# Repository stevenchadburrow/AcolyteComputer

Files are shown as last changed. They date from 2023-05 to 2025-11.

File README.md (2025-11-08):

# AcolyteComputer
Acolyte 6502 "Homebrew" Computer

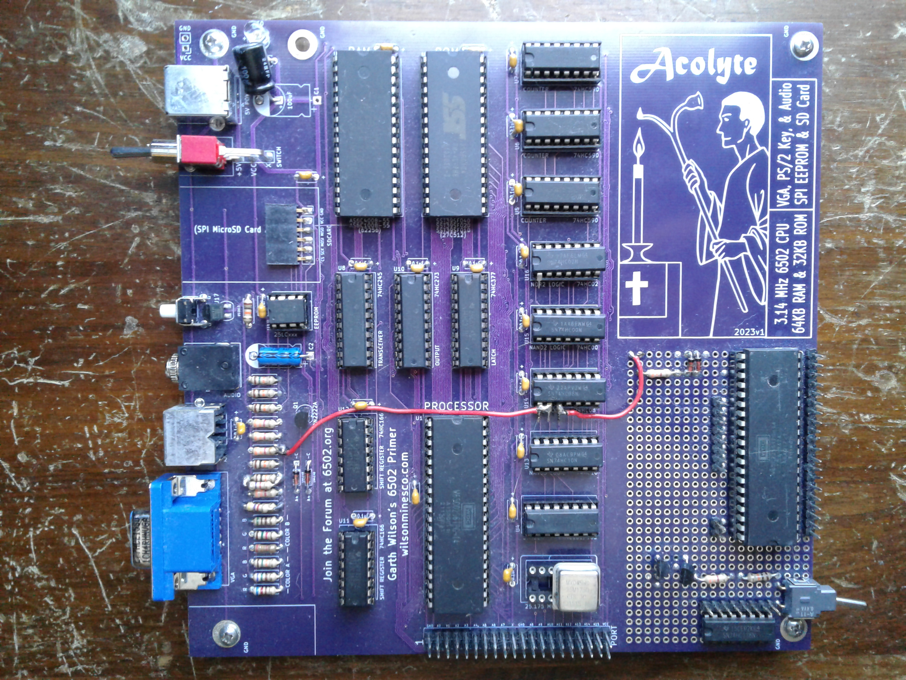
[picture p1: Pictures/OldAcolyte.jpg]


Runs a W65C02 Microprocessor at 3.14 MHz.
Has 64K SRAM and 32K FlashROM.

VGA resolution of 320x240 4-Colors.
PS/2 Keyboard support built in.
One-voice square wave audio.
SPI EEPROM is built into the board.
Socket for a MicroSD Card Adapter.
Optional VIA Expansion.
It is powered with 5V USB.

The goal is that this board would cost less than $100 to assemble.
There are also no CPLD or FPGA chips used, everything besides the 6502/RAM/ROM are 74HC' logic chips.

All files included here are hereby released into the Public Domain.  Anyone is free to copy, modify, publish, use, compile, sell, or distribute these files for any purpose, commercial or non-commercial, and by any means.  These files are provided "as is", without warranty of any kind.  In no event shall the author be liable for any claim, damages, or other liability.

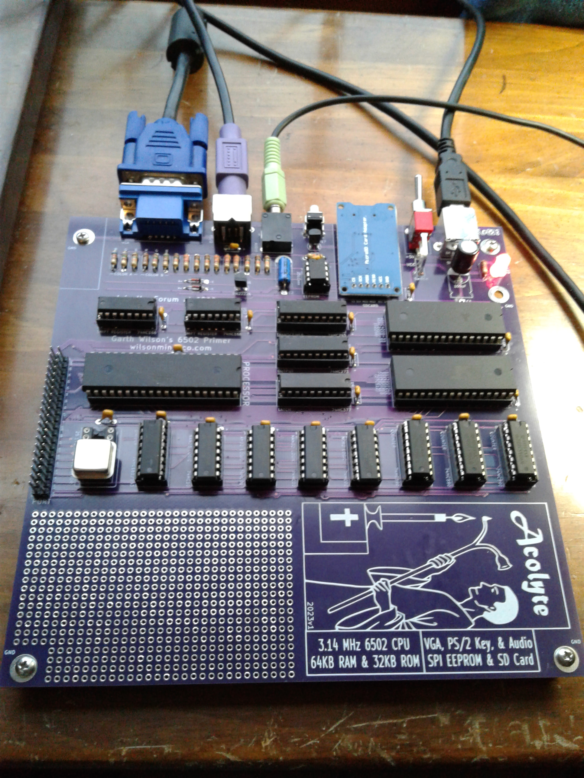
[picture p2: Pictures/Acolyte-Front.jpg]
<br>
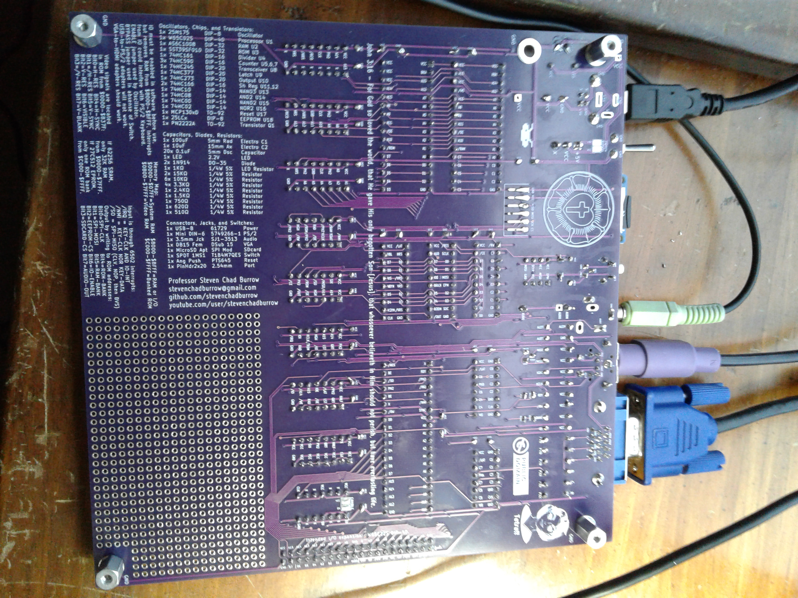
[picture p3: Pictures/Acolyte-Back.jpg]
<br>
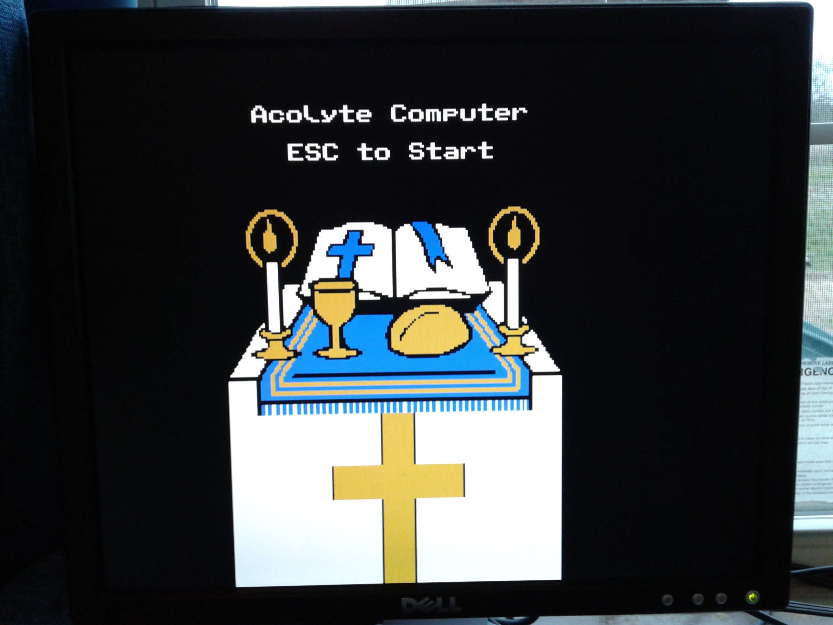
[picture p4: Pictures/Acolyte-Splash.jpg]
<br>
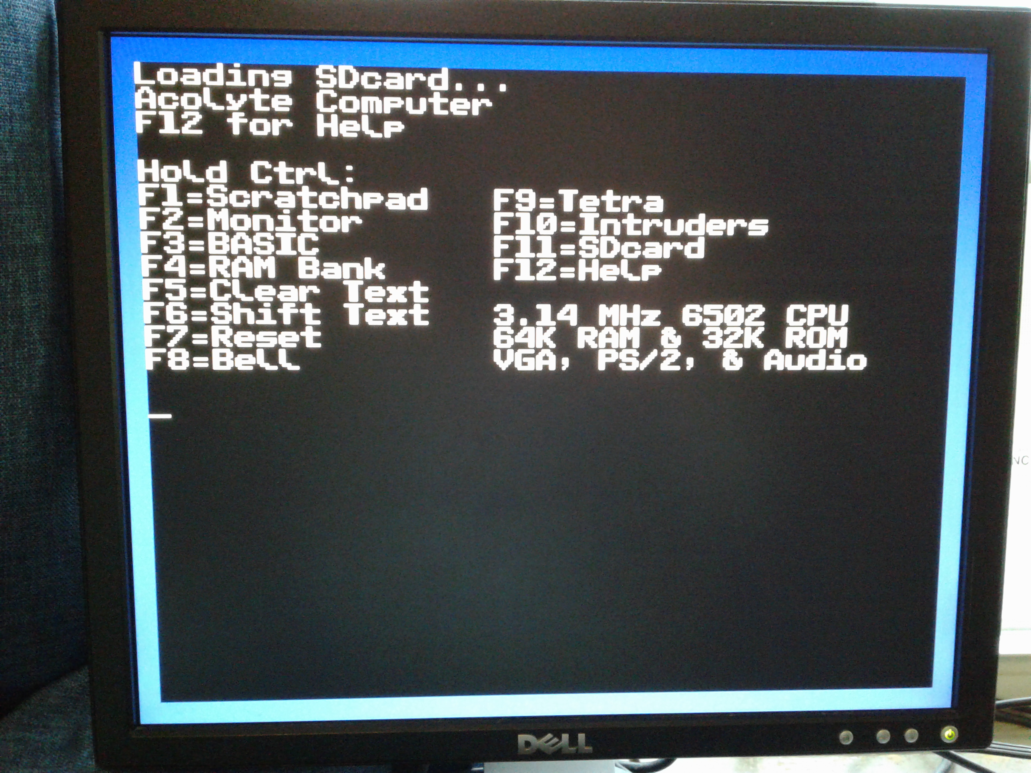
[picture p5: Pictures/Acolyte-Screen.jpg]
<br>

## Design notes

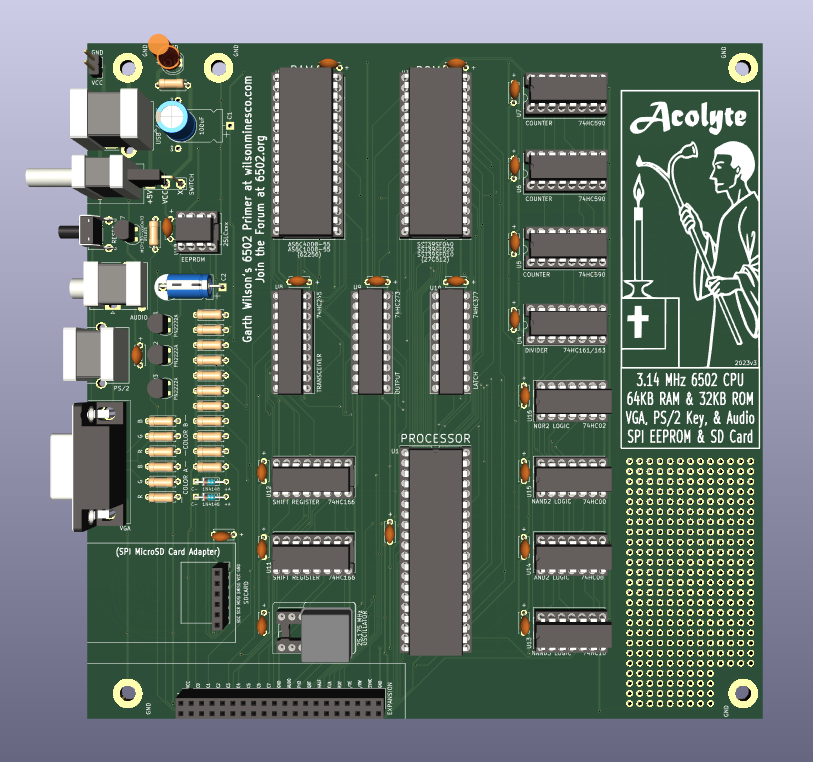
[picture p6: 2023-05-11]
Pictures/AcolyteBoard-Front-Edited.png

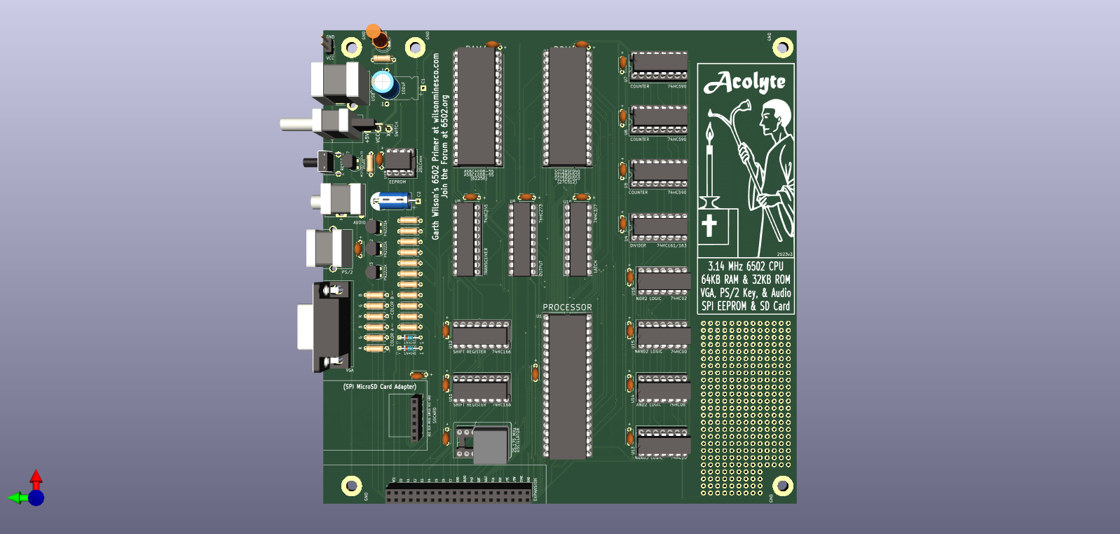
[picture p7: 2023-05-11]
Pictures/AcolyteBoard-Front.png

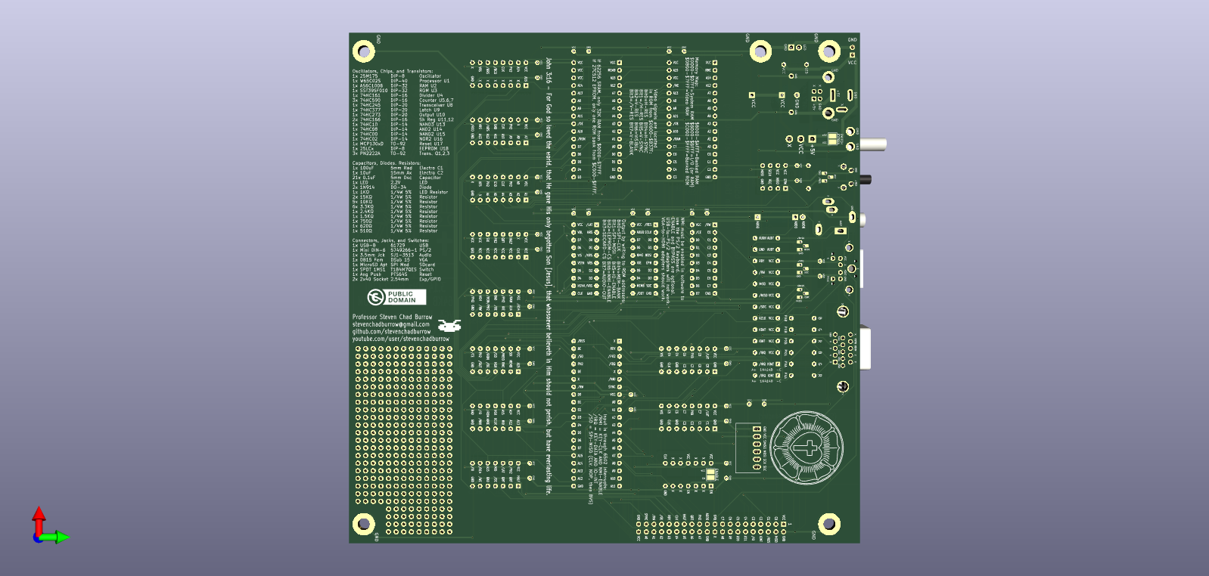
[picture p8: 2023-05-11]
Pictures/AcolyteBoard-Back.png

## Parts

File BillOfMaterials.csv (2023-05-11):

Oscillators, Chips, and Transistors:
1x 25M175 | DIP-8 | Oscillator
1x W65C02S | DIP-40 | Processor U1
1x AS6C1008 | DIP-32 | RAM U2
1x SST39SF010 | DIP-32 | ROM U3
1x 74HC161 | DIP-16 | Divider U4
3x 74HC590 | DIP-16 | Counter U5,6,7
1x 74HC245 | DIP-20 | Transceiver U8
1x 74HC377 | DIP-20 | Latch U9
1x 74HC273 | DIP-20 | Output U10
2x 74HC166 | DIP-16 | Sh Reg U11,12
1x 74HC10 | DIP-14 | NAND3 U13
1x 74HC08 | DIP-14 | AND2 U14
1x 74HC00 | DIP-14 | NAND2 U15
1x 74HC02 | DIP-14 | NOR2 U16
1x MCP130xD | TO-92 | Reset U17
1x 25LCx | DIP-8 | EEPROM U18
3x PN2222A | TO-92 | Trans. Q1,2,3
Capacitors, Diodes, Resistors:
1x 100uF | 5mm Rad | Electro C1
1x 10uF | 15mm Ax | Electro C2
20x 0.1uF | 5mm Dsc | Capacitor
1x LED | 2.2V | LED
2x 1N914 | DO-35 | Diode
1x 1KΩ | 1/4W 5% | LED Resistor
2x 15KΩ | 1/4W 5% | Resistor
5x 10KΩ | 1/4W 5% | Resistor
6x 3.3KΩ | 1/4W 5% | Resistor
1x 2.4KΩ | 1/4W 5% | Resistor
1x 1.5KΩ | 1/4W 5% | Resistor
1x 750Ω | 1/4W 5% | Resistor
1x 620Ω | 1/4W 5% | Resistor
1x 510Ω | 1/4W 5% | Resistor
Connectors, Jacks, and Switches:
1x USB-B | 61729 | Power
1x Mini DIN-6 | 5749266-1 | PS/2
1x 3.5mm Jck | SJ1-3513 | Audio
1x DB15 Fem | DSub 15 | VGA
1x MicroSD Apt | SPI Mod | SDcard
1x SPDT 1MS1 | T1B4M7QES | Switch
1x Ang Push | PTS645 | Reset
1x 2x20 Socket | 2.54mm | Expansion

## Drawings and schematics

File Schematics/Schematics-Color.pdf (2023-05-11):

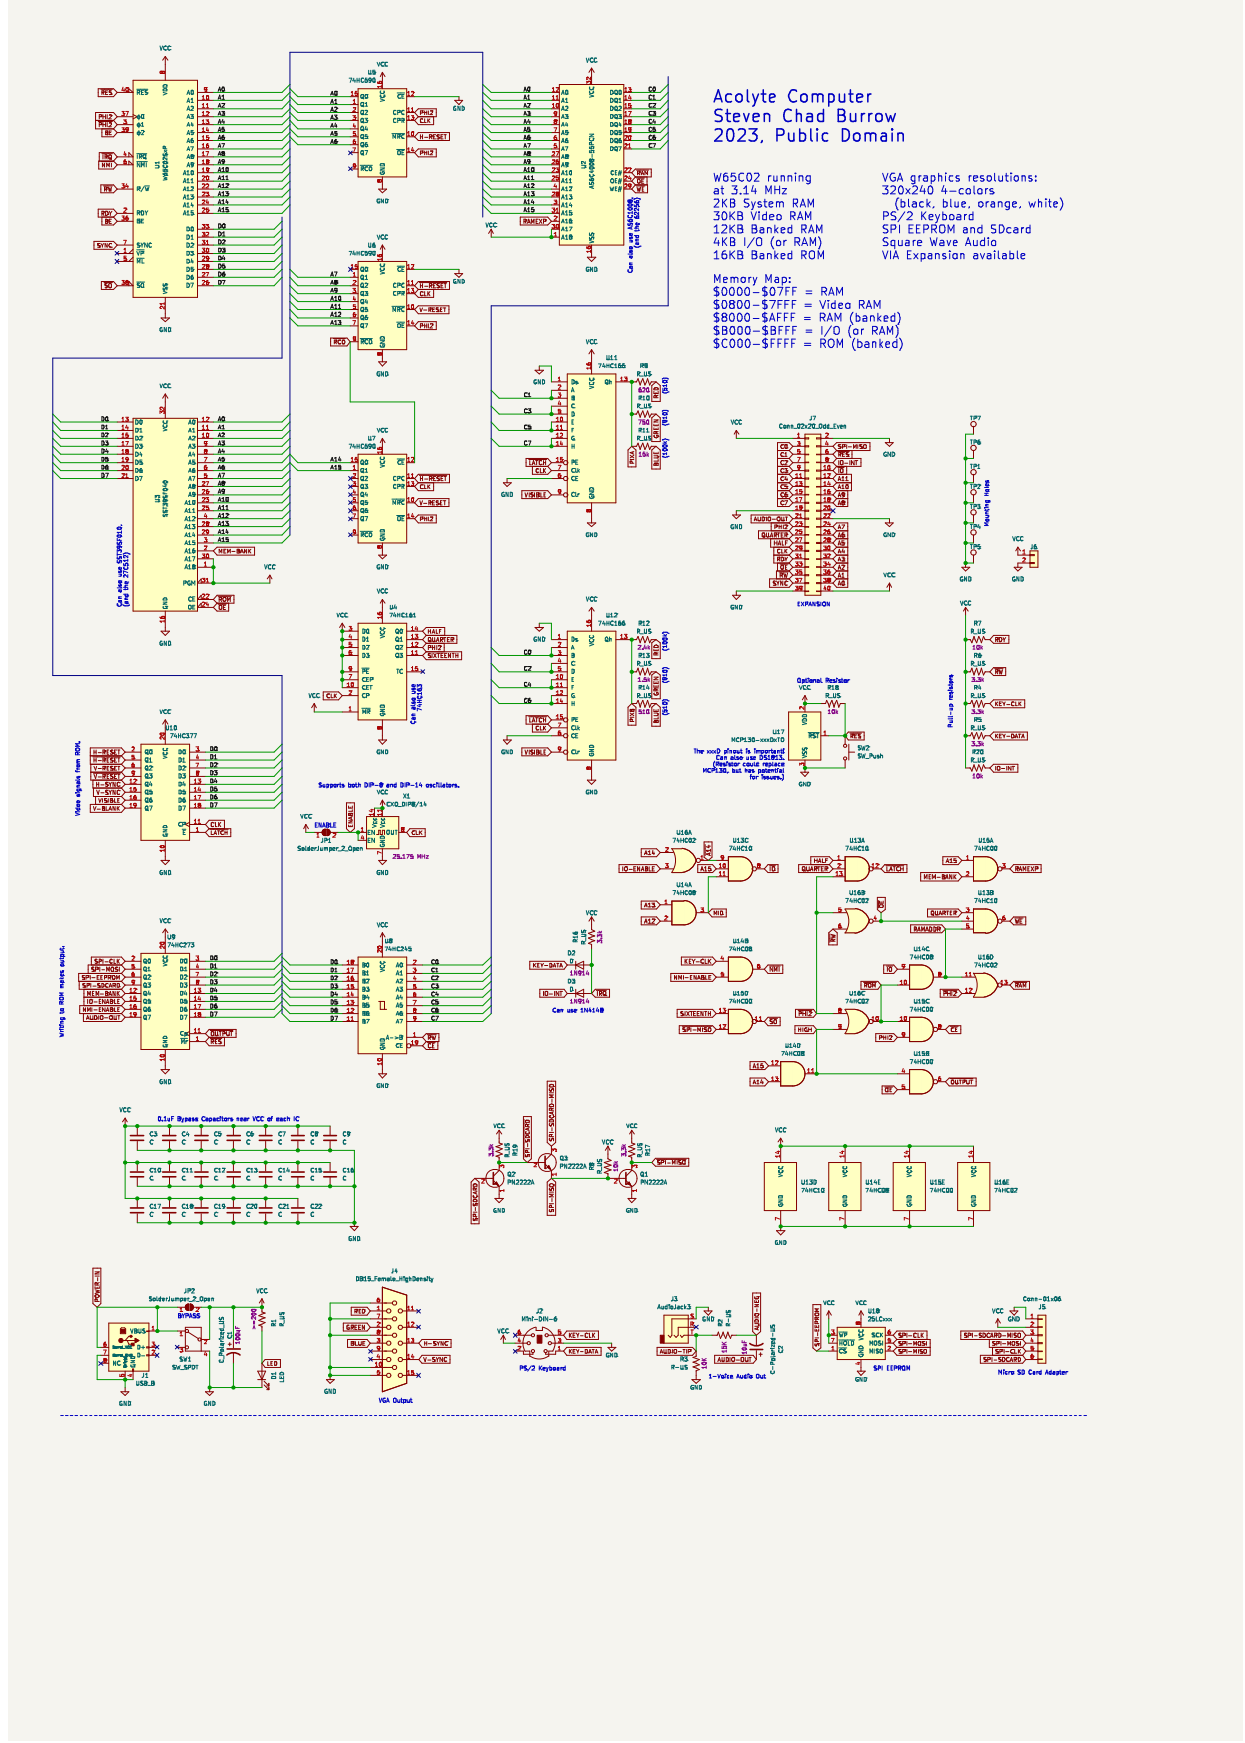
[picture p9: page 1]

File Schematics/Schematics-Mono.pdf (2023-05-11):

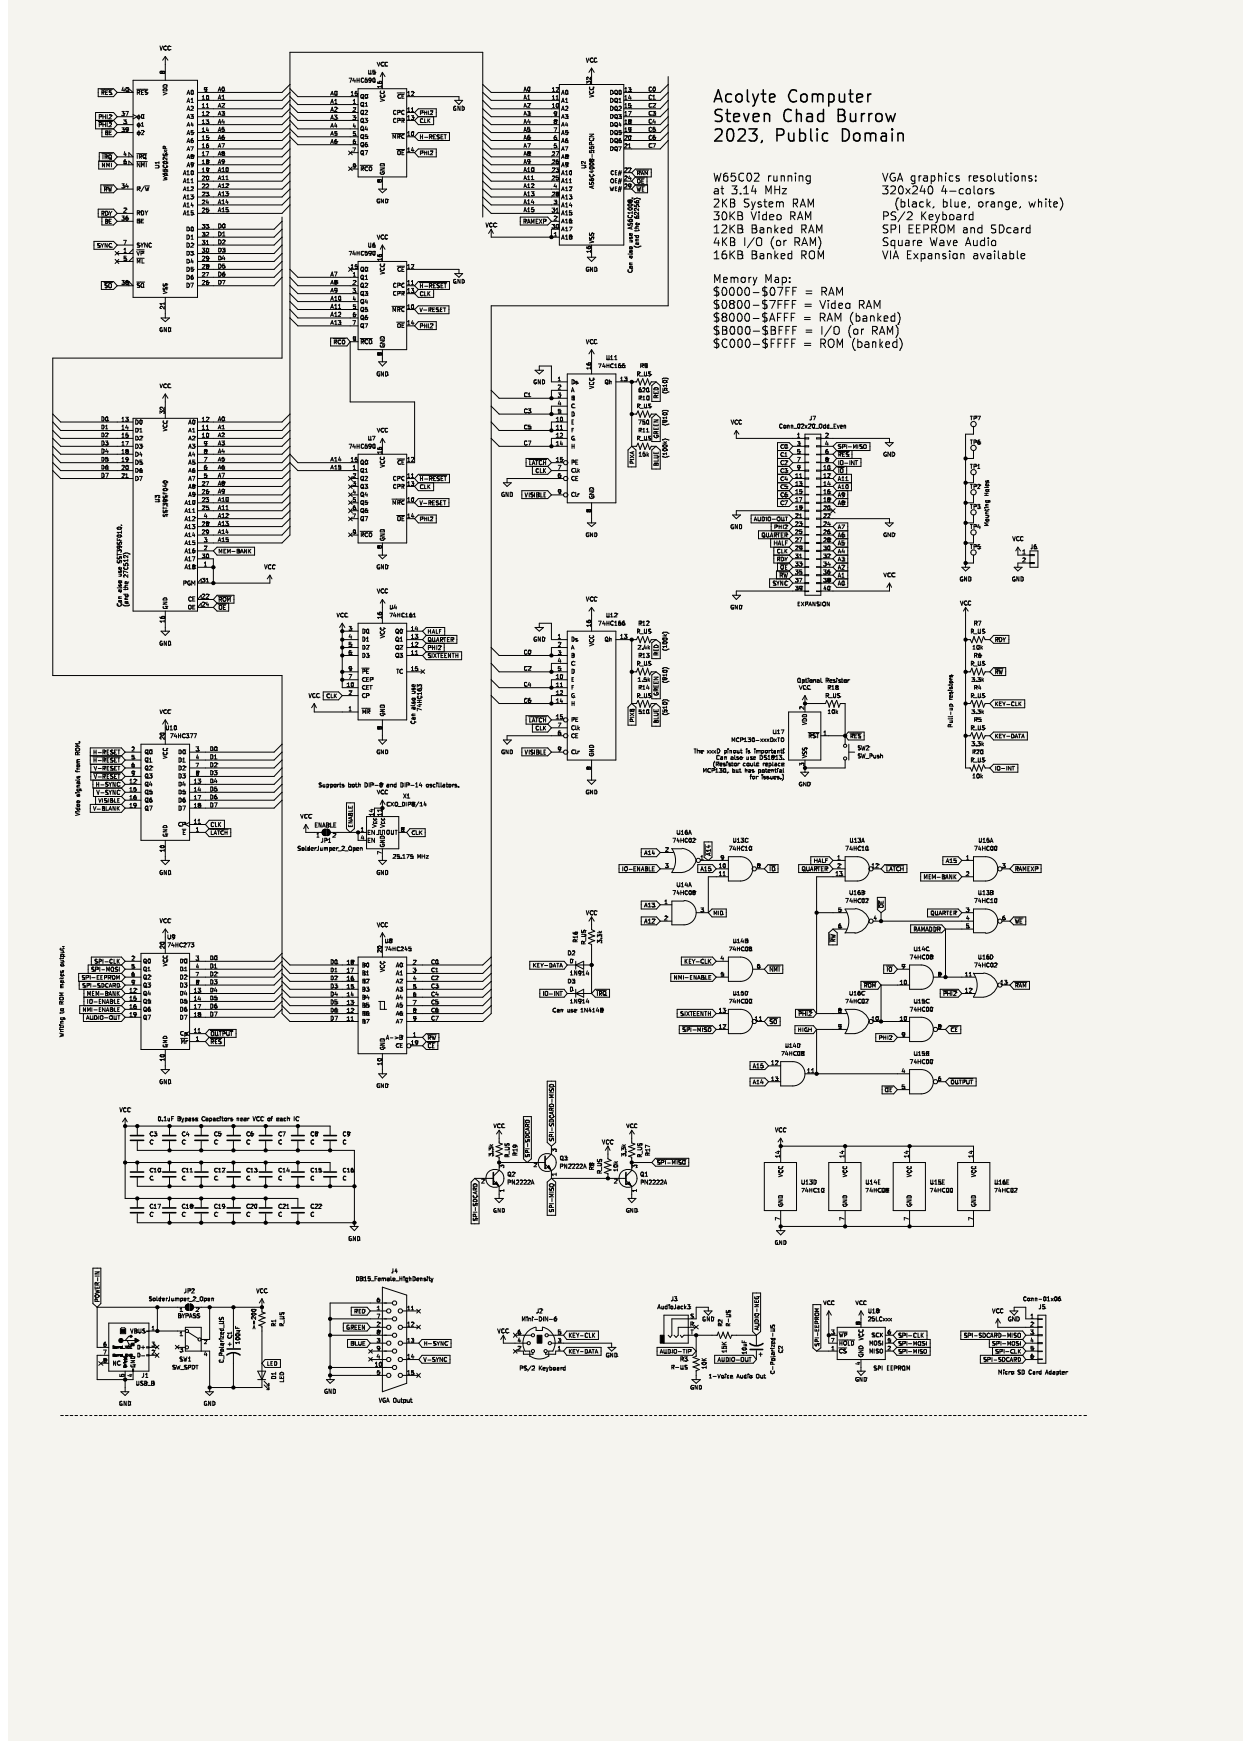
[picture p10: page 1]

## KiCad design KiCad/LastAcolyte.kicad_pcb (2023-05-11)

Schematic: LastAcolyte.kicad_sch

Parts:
C1: C_Polarized_US; Dual Capacitor (Medium)
C2: C-Polarized-US; Dual Electrolytic Capacitor
C3, C4, C5, C6, C7, C8, C9, C10, C11, C12, C13, C14, C15, C16, C17, C18, C19, C20, C21, C22: C; C_Disc_D5.0mm_W2.5mm_P5.00mm
D1: LED; CustomLED
D2, D3: D; WideDiode
J1: USB_B; DualPowerSupply
J2: Mini-DIN-6; PS2_Din6
J3: AudioJack3; BIGJack_3.5mm_Ledino_KB3SPRS_Horizontal
J4: DB15_Female_HighDensity; DSUB-15-HD_Female_Horizontal_P2.29x2.54mm_VGA
J5: Conn-01x06; SDcardPinSocket-Wide
J6: Conn_01x02; PinHeader_1x02_P2.54mm_Vertical
J7: Conn_02x20_Odd_Even; PinSocket_2x20_P2.54mm_Vertical
JP1, JP2: SolderJumper_2_Open; SolderJumper_Testing-2_P1.3mm_Open_Pad1.0x1.5mm
Q1, Q2, Q3: PN2222A; TO-92_HandSolder
R1, R4, R5, R6, R7, R8, R9, R10, R11, R12, R13, R14, R16, R17, R18, R19, R20: R_US; R_Axial_DIN0207_L6.3mm_D2.5mm_P7.62mm_Horizontal
R2, R3: R-US; R_Axial_DIN0207_L6.3mm_D2.5mm_P7.62mm_Horizontal
SW1: SW_SPDT; SPDT-1MS1T1B4M7QES
SW2: SW_Push; SW_Tactile_SPST_Angled_PTS645Vx83-2LFS
TP1, TP2, TP3, TP4, TP5: TestPoint; ScrewHole-4-40
TP6, TP7: TestPoint; CustomTestPoint
U1: W65C02SxP; DIP-40_W15.24mm_Socket
U2: AS6C4008-55PCN; DIP-32_W15.24mm_Socket
U3: SST39SF040; DIP-32_W15.24mm_Socket
U4: 74HC161; DIP-16_W7.62mm_Socket
U5, U6, U7: 74HC590; DIP-16_W7.62mm_Socket
U8: 74HC245; DIP-20_W7.62mm_Socket
U9: 74HC273; DIP-20_W7.62mm_Socket
U10: 74HC377; DIP-20_W7.62mm_Socket
U11, U12: 74HC166; DIP-16_W7.62mm_Socket
U13: 74HC10; DIP-14_W7.62mm_Socket
U14: 74HC08; DIP-14_W7.62mm_Socket
U15: 74HC00; DIP-14_W7.62mm_Socket
U16: 74HC02; DIP-14_W7.62mm_Socket
U17: MCP130-xxxDxTO; TO-92_HandSolder
U18: 25LCxxx; DIP-8_W7.62mm_Socket
X1: CXO_DIP8/14; DualOscillator

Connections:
+5V: C1.1, C3.1, C4.1, C5.1, C6.1, C7.1, C8.1, C9.1, C10.1, C11.1, C12.1, C13.1, C14.1, C15.1, C16.1, C17.1, C18.1, C19.1, C20.1, C21.1, C22.1, J2.4, J5.2, J6.1, J7.1, J7.40, JP1.1 (A), JP2.2 (B), R1.2, R4.1, R5.1, R6.1, R7.2, R8.2, R16.2, R17.1, R18.1, R19.1, R20.2, SW1.2 (B), U1.8 (VDD), U2.1 (A18), U2.30 (A17), U2.32 (VCC), U3.1 (A18), U3.30 (A17), U3.31 (PGM), U3.32 (VCC), U4.1 (~MR), U4.3 (D0), U4.4 (D1), U4.5 (D2), U4.6 (D3), U4.7 (CEP), U4.9 (~PE), U4.10 (CET), U4.16 (VCC), U5.16 (VCC), U6.16 (VCC), U7.16 (VCC), U8.20 (VCC), U9.20 (VCC), U10.20 (VCC), U11.16 (VCC), U12.16 (VCC), U13.14 (VCC), U14.14 (VCC), U15.14 (VCC), U16.14 (VCC), U17.2 (VDD), U18.3 (~WP), U18.7 (~HOLD), U18.8 (VCC), X1.11 (Vcc), X1.14 (Vcc)
/D0: U1.33 (D0), U3.13 (D0), U8.18 (B0), U9.3 (D0), U10.3 (D0)
/D1: U1.32 (D1), U3.14 (D1), U8.17 (B1), U9.4 (D1), U10.4 (D1)
/D2: U1.31 (D2), U3.15 (D2), U8.16 (B2), U9.7 (D2), U10.7 (D2)
/D3: U1.30 (D3), U3.17 (D3), U8.15 (B3), U9.8 (D3), U10.8 (D3)
/D4: U1.29 (D4), U3.18 (D4), U8.14 (B4), U9.13 (D4), U10.13 (D4)
/D5: U1.28 (D5), U3.19 (D5), U8.13 (B5), U9.14 (D5), U10.14 (D5)
/D6: U1.27 (D6), U3.20 (D6), U8.12 (B6), U9.17 (D6), U10.17 (D6)
/D7: U1.26 (D7), U3.21 (D7), U8.11 (B7), U9.18 (D7), U10.18 (D7)
A0: J7.38, U1.9 (A0), U2.12 (A0), U3.12 (A0), U5.15 (Q0)
A1: J7.36, U1.10 (A1), U2.11 (A1), U3.11 (A1), U5.1 (Q1)
A2: J7.34, U1.11 (A2), U2.10 (A2), U3.10 (A2), U5.2 (Q2)
A3: J7.32, U1.12 (A3), U2.9 (A3), U3.9 (A3), U5.3 (Q3)
A4: J7.30, U1.13 (A4), U2.8 (A4), U3.8 (A4), U5.4 (Q4)
A5: J7.28, U1.14 (A5), U2.7 (A5), U3.7 (A5), U5.5 (Q5)
A6: J7.26, U1.15 (A6), U2.6 (A6), U3.6 (A6), U5.6 (Q6)
A7: J7.24, U1.16 (A7), U2.5 (A7), U3.5 (A7), U6.1 (Q1)
A8: J7.18, U1.17 (A8), U2.27 (A8), U3.27 (A8), U6.2 (Q2)
A9: J7.16, U1.18 (A9), U2.26 (A9), U3.26 (A9), U6.3 (Q3)
A10: J7.14, U1.19 (A10), U2.23 (A10), U3.23 (A10), U6.4 (Q4)
A11: J7.12, U1.20 (A11), U2.25 (A11), U3.25 (A11), U6.5 (Q5)
A12: U1.22 (A12), U2.4 (A12), U3.4 (A12), U6.6 (Q6), U14.2
A13: U1.23 (A13), U2.28 (A13), U3.28 (A13), U6.7 (Q7), U14.1
A14: U1.24 (A14), U2.3 (A14), U3.29 (A14), U7.15 (Q0), U14.13, U16.2
A15: U1.25 (A15), U2.31 (A15), U3.3 (A15), U7.1 (Q1), U13.10, U14.12, U15.1
AUDIO-NEG: C2.2, R2.2
AUDIO-OUT: C2.1, J7.21, U9.19 (Q7)
AUDIO-TIP: J3.T, R2.1, R3.1
BE: U1.36 (BE), U1.39 (ϕ2)
BLUE: J4.3, R11.2, R14.2
C0: J7.3, U2.13 (DQ0), U8.2 (A0), U12.2 (A), U12.3 (B)
C1: J7.5, U2.14 (DQ1), U8.3 (A1), U11.2 (A), U11.3 (B)
C2: J7.7, U2.15 (DQ2), U8.4 (A2), U12.4 (C), U12.5 (D)
C3: J7.9, U2.17 (DQ3), U8.5 (A3), U11.4 (C), U11.5 (D)
C4: J7.11, U2.18 (DQ4), U8.6 (A4), U12.10 (E), U12.11 (F)
C5: J7.13, U2.19 (DQ5), U8.7 (A5), U11.10 (E), U11.11 (F)
C6: J7.15, U2.20 (DQ6), U8.8 (A6), U12.12 (G), U12.14 (H)
C7: J7.17, U2.21 (DQ7), U8.9 (A7), U11.12 (G), U11.14 (H)
CLK: J7.29, U4.2 (CP), U5.13 (CPR), U6.13 (CPR), U7.13 (CPR), U10.11 (CP), U11.7 (Clk), U12.7 (Clk), X1.8 (OUT)
ENABLE: JP1.2 (B), X1.1 (EN), X1.4 (EN)
GND: C1.2, C3.2, C4.2, C5.2, C6.2, C7.2, C8.2, C9.2, C10.2, C11.2, C12.2, C13.2, C14.2, C15.2, C16.2, C17.2, C18.2, C19.2, C20.2, C21.2, C22.2, D1.1 (K), J1.4 (GND), J1.5 (Shield), J1.7 (Barrel_GND), J2.3, J3.S, J4.5, J4.6, J4.7, J4.8, J4.10, J5.1, J6.2, J7.2, J7.19, J7.22, J7.39, Q1.1 (E), Q2.1 (E), R3.2, SW1.4 (Shield), SW2.2, TP1.1, TP2.1, TP3.1, TP4.1, TP5.1, TP6.1, TP7.1, U1.21 (VSS), U2.16 (VSS), U3.16 (GND), U4.8 (GND), U5.8 (GND), U5.12 (~CE), U6.8 (GND), U6.12 (~CE), U7.8 (GND), U8.10 (GND), U9.10 (GND), U10.10 (GND), U11.1 (Ds), U11.6 (CE), U11.8 (GND), U12.1 (Ds), U12.6 (CE), U12.8 (GND), U13.7 (GND), U14.7 (GND), U15.7 (GND), U16.7 (GND), U17.3 (VSS), U18.4 (GND), X1.7 (GND)
GREEN: J4.2, R10.2, R13.2
H-RESET: U5.10 (~MRC), U10.2 (Q0)
H-SYNC: J4.13, U10.12 (Q4)
HALF: J7.27, U4.14 (Q0), U13.1
HIGH: U14.11, U15.4, U16.9
IO-ENABLE: U9.15 (Q5), U16.3
IO-INT: D3.1 (K), J7.8, R20.1
KEY-CLK: J2.5, R4.2, U14.4
KEY-DATA: D2.1 (K), J2.1, R5.2
LED: D1.2 (A), R1.1
MEM-BANK: U3.2 (A16), U9.12 (Q4), U15.2
MID: U13.11, U14.3
NMI-ENABLE: U9.16 (Q6), U14.5
PHI2: J7.23, U1.37 (ϕ0), U4.12 (Q2), U5.11 (CPC), U5.14 (~OE), U6.14 (~OE), U7.14 (~OE), U15.9
PIXA: R9.1, R10.1, R11.1, U11.13 (Qh)
PIXB: R12.1, R13.1, R14.1, U12.13 (Qh)
POWER-IN: J1.1 (VBUS), J1.6 (Barrel_VCC), JP2.1 (A), SW1.1 (A)
QUARTER: J7.25, U4.13 (Q1), U13.2, U13.3
RAMADDR: U13.5, U14.8, U16.11
RAMEXP: U2.2 (A16), U15.3
RDY: J7.31, R7.1, U1.2 (RDY)
RED: J4.1, R9.2, R12.2
SIXTEENTH: U4.11 (Q3), U15.13
SPI-CLK: J5.5, U9.2 (Q0), U18.6 (SCK)
SPI-EEPROM: U9.6 (Q2), U18.1 (~CS)
SPI-MISO: J7.4, Q1.2 (B), Q3.1 (E), R8.1, U18.2 (MISO)
SPI-MOSI: J5.4, U9.5 (Q1), U18.5 (MOSI)
SPI-SDCARD: J5.6, Q2.2 (B), U9.9 (Q3)
SPI-SDCARD-MISO: J5.3, Q3.3 (C)
SYNC: J7.37, U1.7 (SYNC)
V-BLANK: U10.19 (Q7)
V-RESET: U6.10 (~MRC), U7.10 (~MRC), U10.6 (Q2)
V-SYNC: J4.14, U10.15 (Q5)
VISIBLE: U10.16 (Q6), U11.9 (Clr), U12.9 (Clr)
~A14: U13.9, U16.1
~CE: U8.19 (CE), U15.8
~H-RESET: U6.11 (CPC), U7.11 (CPC), U10.5 (Q1)
~IO: J7.10, U13.8, U14.9
~IRQ: D2.2 (A), D3.2 (A), R16.1, U1.4 (~IRQ)
~LATCH: U10.1 (~E), U11.15 (PE), U12.15 (PE), U13.12
~NMI: U1.6 (~NMI), U14.6
~OE: J7.33, U2.24 (OE#), U3.24 (OE), U13.4, U15.5, U16.4
~OUTPUT: U9.11 (Cp), U15.6
~PHI2: U1.3 (ϕ1), U13.13, U16.5, U16.8, U16.12
~RAM: U2.22 (CE#), U16.13
~RCO: U6.9 (~RCO), U7.12 (~CE)
~RES: J7.6, R18.2, SW2.1, U1.40 (~RES), U9.1 (~Mr), U17.1 (~RST)
~ROM: U3.22 (CE), U14.10, U15.10, U16.10
~RW: J7.35, R6.2, U1.34 (R/~W), U8.1 (A->B), U16.6
~SO: U1.38 (~SO), U15.11
~SPI-MISO: Q1.3 (C), R17.2, U15.12
~SPI-SDCARD: Q2.3 (C), Q3.2 (B), R19.2
~V-RESET: U10.9 (Q3)
~WE: U2.29 (WE#), U13.6

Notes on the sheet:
W65C02 running at 3.14 MHz 2KB System RAM 30KB Video RAM 12KB Banked RAM 4KB I/O (or RAM) 16KB Banked ROM
Video signals from ROM.
0.1uF Bypass Capacitors near VCC of each IC
Acolyte Computer Steven Chad Burrow 2023, Public Domain
~{CS2}
EXPANSION
Reading from RAM
(910)
Can also use AS6C1008, (and the 62256)
Optional Resistor
$8380
Can also use SST39SF010, (and the 27C512)
RS0
1-Voice Audio Out
Micro SD Card Adapter
RS3
$0000
Can also use 74HC163
Upper/Lower Addresses
Video
Visible Area
The xxxD pinout is important! Can also use DS1813. (Resistor could replace MCP130, but has potential for issues.)
(510)
Start Bit=0
Horizontal Back Porch
Can use 1N4148
Writing to RAM
Horizontal Front Porch
Horizontal Sync
Write Byte
Supports both DIP-8 and DIP-14 oscillators.
VGA Output
(100k)
$8000
Writing to ROM makes output.
Pull-up resistors
R/~{W}
~{RES}
Read Command
Writing to ROM (causes Output)

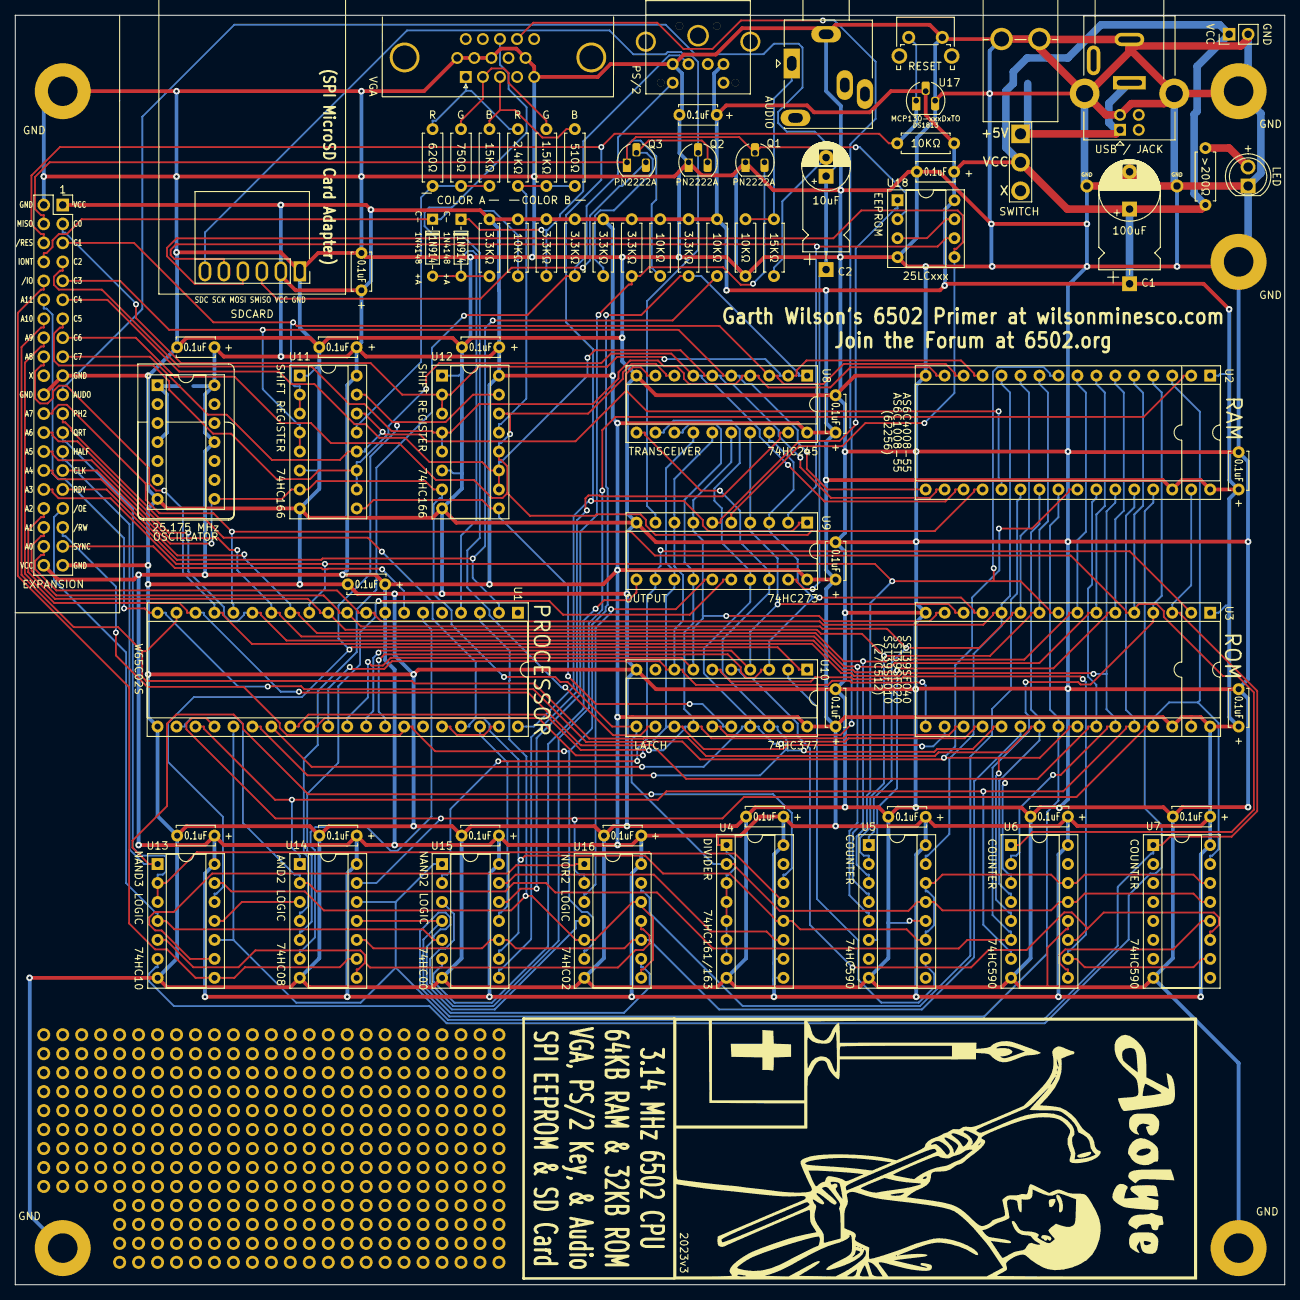
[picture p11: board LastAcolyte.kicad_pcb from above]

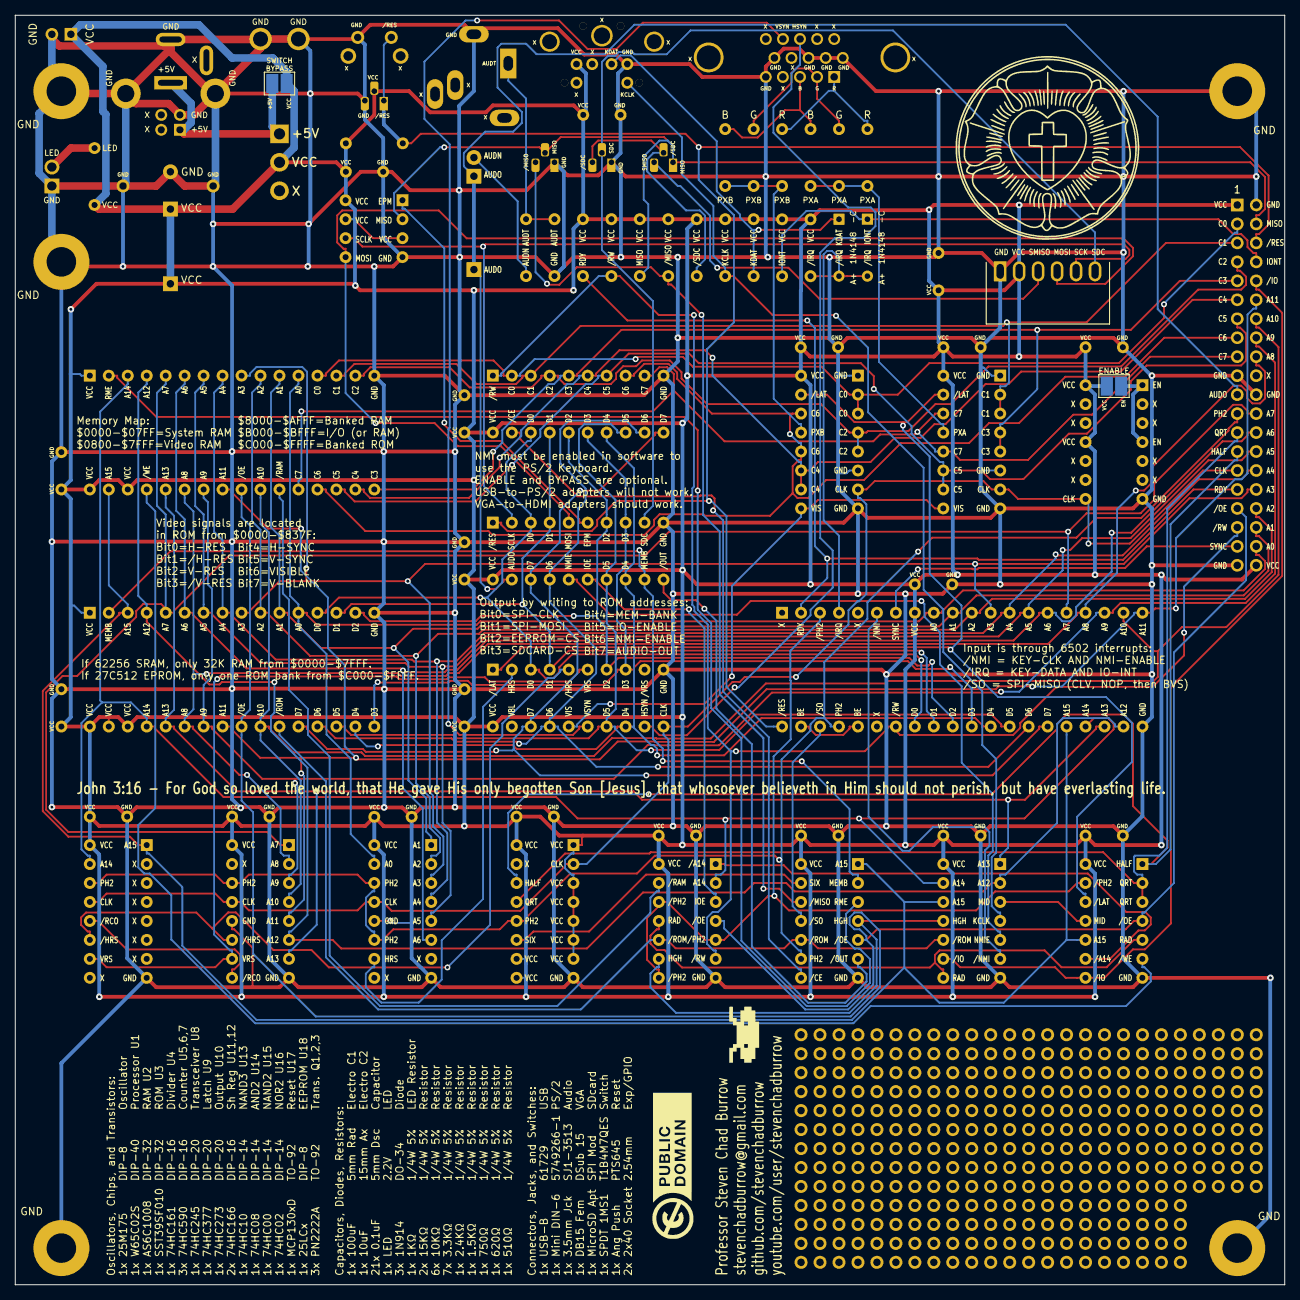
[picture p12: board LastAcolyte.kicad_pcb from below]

Board: 2 copper layers, 170.0 x 170.0 mm, 88 parts (5 on the bottom side), 93 nets.

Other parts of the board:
G99: LOGO; AcolyteLogoSmall
G995: LOGO; LutheranRosePD
G997: LOGO; Mystery
G998: LOGO; PublicDomain

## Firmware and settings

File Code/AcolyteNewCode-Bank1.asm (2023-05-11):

; Acolyte Computer Code


; First, run
; ~/dev65/bin/as65 AcolyteNewCode-Bank1.asm

; Second, run
; ./Parser.o AcolyteNewCode-Bank1.lst AcolyteNewCode-Bank1.bin 32768 32768 32768 0

; Third (for second bank), run
; ~/dev65/bin/as65 AcolyteNewCode-Bank2.asm

; Fourth (for second bank), run
; ./Parser.o AcolyteNewCode-Bank2.lst AcolyteNewCode-Bank2.bin 32768 32768 32768 0

; Fifth, run
; ./Combiner.o VideoROM.bin AcolyteNewCode-Bank1.bin AcolyteNewCode-Bank2.bin AcolyteCode-128K.bin AcolyteCode-512K.bin

; OR, all together
; ~/dev65/bin/as65 AcolyteNewCode-Bank1.asm ; ./Parser.o AcolyteNewCode-Bank1.lst AcolyteNewCode-Bank1.bin 32768 32768 32768 0 ; ~/dev65/bin/as65 AcolyteNewCode-Bank2.asm ; ./Parser.o AcolyteNewCode-Bank2.lst AcolyteNewCode-Bank2.bin 32768 32768 32768 0 ; ./Combiner.o VideoROM.bin AcolyteNewCode-Bank1.bin AcolyteNewCode-Bank2.bin AcolyteCode-128K.bin AcolyteCode-512K.bin

; Sixth, run
; minipro -p "SST39SF010" -w AcolyteCode-128K.bin




; Acolyte Computer

; Running a W65C02 at 3.14 MHz

; VGA display at
; 320x240 4-color

; Support for
; PS/2 Keyboard
; SPI SDcard
; SPI EEPROM
; Square Wave Audio

; Memory Map
; $0000-$01FF = Zero Page / Stack
; $0200-$07FF = System RAM
; $0800-$7FFF = Video RAM
; $8000-$AFFF = General Purpose Banked RAM
; $B000-$BFFF = I/O Space (or RAM)
; $C000-$FFFF = ROM (2x banks)

; Writing to ROM produces output
; D0 = SPI-CLK
; D1 = SPI-MOSI
; D2 = SPI-EEPROM
; D3 = SPI-SDCARD
; D4 = MEM-BANK (both RAM and ROM)
; D5 = IO-ENABLE
; D6 = NMI-ENABLE
; D7 = AUDIO-OUT

; Writing to ROM also writes to RAM if the RAM is fast enough.
; This is not a problem when using the 128KB RAM, but when using
; only 32KB of RAM, it would show anything written to ROM in 
; the RAM space given.  So, when writing to ROM for output,
; make sure to write to $FFFF which is off-screen and is not 
; expected to be used.

; Input is through interrupts and /SO
; /NMI = KEY-CLK (can be disabled)
; /IRQ = KEY-DATA (and other interrupt sources)
; /SO = toggles when SPI-MISO is low

; Keyboard can be turned off by doing
; STZ key_status
; CLI
; Those together will lock the keyboard functionality,
; but allow /IRQ to be used by some other source.
; To turn the keyboard back on you would
; LDA #$01
; STA key_status
; SEI




	.65C02

; PS/2 Keyboard Keycodes
ps2_return		.EQU $5A
ps2_backspace		.EQU $66
ps2_escape		.EQU $76
ps2_shift_left		.EQU $12
ps2_shift_right		.EQU $59
ps2_capslock		.EQU $58
ps2_numlock		.EQU $77
ps2_scrolllock		.EQU $7E
ps2_control		.EQU $14
ps2_alt			.EQU $11
ps2_tab			.EQU $0D
ps2_page_up		.EQU $7D
ps2_page_down		.EQU $7A
ps2_arrow_up		.EQU $75
ps2_arrow_down		.EQU $72
ps2_arrow_left		.EQU $6B
ps2_arrow_right		.EQU $74
ps2_insert		.EQU $70
ps2_delete		.EQU $71
ps2_home		.EQU $6C
ps2_end			.EQU $69
ps2_slash		.EQU $4A
ps2_f1			.EQU $05
ps2_f2			.EQU $06
ps2_f3			.EQU $04
ps2_f4			.EQU $0C
ps2_f5			.EQU $03
ps2_f6			.EQU $0B
ps2_f7			.EQU $83
ps2_f8			.EQU $0A
ps2_f9			.EQU $01
ps2_f10			.EQU $09
ps2_f11			.EQU $78
ps2_f12			.EQU $07


; System RAM locations


key_array		.EQU $0200
key_error		.EQU $0280

key_write		.EQU $0300
key_read		.EQU $0301
key_data		.EQU $0302
key_counter		.EQU $0303
key_release		.EQU $0304
key_extended		.EQU $0305
key_shift		.EQU $0306
key_capslock		.EQU $0307
key_alt_control		.EQU $0308
key_code		.EQU $0309
key_status		.EQU $030A ; unused

printchar_x		.EQU $030B
printchar_y		.EQU $030C
printchar_invert	.EQU $030D

inputchar_value		.EQU $030E

spi_cs_enable		.EQU $030F

sub_read		.EQU $0310
sub_write		.EQU $0314
sub_jump		.EQU $0318
sub_index		.EQU $031C

command_mode		.EQU $0320
command_addr1_low	.EQU $0321
command_addr1_high	.EQU $0322
command_addr2_low	.EQU $0323
command_addr2_high	.EQU $0324
command_addr3_low	.EQU $0325
command_addr3_high	.EQU $0326
command_addr4_low	.EQU $0327
command_addr4_high	.EQU $0328
command_data		.EQU $0329
command_byte1		.EQU $032A
command_byte2		.EQU $032B
command_byte3		.EQU $032C
command_place		.EQU $032D
command_function	.EQU $032E
command_temp		.EQU $032F

basic_counter		.EQU $0330
basic_addr_low		.EQU $0331
basic_addr_high		.EQU $0332
basic_data		.EQU $0333
basic_first		.EQU $0334
basic_bytes		.EQU $0335
basic_var_low		.EQU $0336
basic_var_high		.EQU $0337
basic_nested		.EQU $0338
basic_operator		.EQU $0339
basic_next		.EQU $033A
basic_compare_first	.EQU $033B
basic_compare_second	.EQU $033C
basic_compare_operator	.EQU $033D
basic_colon		.EQU $033E
basic_quotes		.EQU $033F
basic_counter_change	.EQU $0340
basic_rts_low1		.EQU $0341
basic_rts_high1		.EQU $0342
basic_rts_low2		.EQU $0343
basic_rts_high2		.EQU $0344
basic_sub_random	.EQU $0345
basic_sub_random_var	.EQU $0356

output_byte		.EQU $0357

basic_user_array	.EQU $0358 ; 8 bytes long

jump_printchar		.EQU $0360 ; jump sub-routines for ease of programming
jump_inputchar		.EQU $0368
jump_spi_eeprom_write	.EQU $0370
jump_spi_eeprom_read	.EQU $0378
jump_spi_sdcard_init	.EQU $0380
jump_spi_sdcard_read	.EQU $0388

jump_vector_nmi		.EQU $0390
jump_vector_irq		.EQU $0398
jump_vector_irq_extra	.EQU $03A0 ; 16 bytes here

command_array_prev	.EQU $03B0
command_array		.EQU $03D8 ; 40 characters til end

sdcard_memory		.EQU $0400 ; shared with game_field

screen 			.EQU $0800

basic_A			.EQU $8000
basic_B			.EQU $8100
basic_C			.EQU $8200
basic_D			.EQU $8300
basic_W			.EQU $8400
basic_X			.EQU $8500
basic_Y			.EQU $8600
basic_Z			.EQU $8700
basic_code		.EQU $8800
basic_code_end		.EQU $AFFF
basic_code_error	.EQU $B000 ; one past



; the start of code

	.ORG $C000
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
